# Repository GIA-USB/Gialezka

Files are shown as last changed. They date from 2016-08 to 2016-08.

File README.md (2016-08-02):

# Gialezka
Robot autónomo que realiza un recorrido sobre líneas de transmisión simuladas.

Logró el Primer Lugar en la categoría Desafío de la V Competencia Nacional de Robótica UNETBots 2015, realizada en Táchira, Venezuela.

El robot fue realizado por: Raúl Bander, Lalezka Duque, David Hernández y Catherine Lollett

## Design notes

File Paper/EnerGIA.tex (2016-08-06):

%% bare_conf.tex
%% V1.3
%% 2007/01/11
%% by Michael Shell
%% See:
%% http://www.michaelshell.org/
%% for current contact information.
%%
%% This is a skeleton file demonstrating the use of IEEEtran.cls
%% (requires IEEEtran.cls version 1.7 or later) with an IEEE conference paper.
%%
%% Support sites:
%% http://www.michaelshell.org/tex/ieeetran/
%% http://www.ctan.org/tex-archive/macros/latex/contrib/IEEEtran/
%% and
%% http://www.ieee.org/

%%*************************************************************************
%% Legal Notice:
%% This code is offered as-is without any warranty either expressed or
%% implied; without even the implied warranty of MERCHANTABILITY or
%% FITNESS FOR A PARTICULAR PURPOSE! 
%% User assumes all risk.
%% In no event shall IEEE or any contributor to this code be liable for
%% any damages or losses, including, but not limited to, incidental,
%% consequential, or any other damages, resulting from the use or misuse
%% of any information contained here.
%%
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
% the amount of white space around the subfigures. subfigure.sty is already
% installed on most LaTeX systems. The latest version and documentation can
% be obtained at:
% http://www.ctan.org/tex-archive/obsolete/macros/latex/contrib/subfigure/
% subfigure.sty has been superceeded by subfig.sty.

%\usepackage[caption=false]{caption}
%\usepackage[font=footnotesize]{subfig}
% subfig.sty, also written by Steven Douglas Cochran, is the modern
% replacement for subfigure.sty. However, subfig.sty requires and
% automatically loads Axel Sommerfeldt's caption.sty which will override
% IEEEtran.cls handling of captions and this will result in nonIEEE style
% figure/table captions. To prevent this problem, be sure and preload
% caption.sty with its "caption=false" package option. This is will preserve
% IEEEtran.cls handing of captions. Version 1.3 (2005/06/28) and later 
% (recommended due to many improvements over 1.2) of subfig.sty supports
% the caption=false option directly:
%\usepackage[caption=false,font=footnotesize]{subfig}
%
% The latest version and documentation can be obtained at:
% http://www.ctan.org/tex-archive/macros/latex/contrib/subfig/
% The latest version and documentation of caption.sty can be obtained at:
% http://www.ctan.org/tex-archive/macros/latex/contrib/caption/

% *** FLOAT PACKAGES ***
%
%\usepackage{fixltx2e}
% fixltx2e, the successor to the earlier fix2col.sty, was written by
% Frank Mittelbach and David Carlisle. This package corrects a few problems
% in the LaTeX2e kernel, the most notable of which is that in current
% LaTeX2e releases, the ordering of single and double column floats is not
% guaranteed to be preserved. Thus, an unpatched LaTeX2e can allow a
% single column figure to be placed prior to an earlier double column
% figure. The latest version and documentation can be found at:
% http://www.ctan.org/tex-archive/macros/latex/base/

%\usepackage{stfloats}
% stfloats.sty was written by Sigitas Tolusis. This package gives LaTeX2e
% the ability to do double column floats at the bottom of the page as well
% as the top. (e.g., "\begin{figure*}[!b]" is not normally possible in
% LaTeX2e). It also provides a command:
%\fnbelowfloat
% to enable the placement of footnotes below bottom floats (the standard
% LaTeX2e kernel puts them above bottom floats). This is an invasive package
% which rewrites many portions of the LaTeX2e float routines. It may not work
% with other packages that modify the LaTeX2e float routines. The latest
% version and documentation can be obtained at:
% http://www.ctan.org/tex-archive/macros/latex/contrib/sttools/
% Documentation is contained in the stfloats.sty comments as well as in the
% presfull.pdf file. Do not use the stfloats baselinefloat ability as IEEE
% does not allow \baselineskip to stretch. Authors submitting work to the
% IEEE should note that IEEE rarely uses double column equations and
% that authors should try to avoid such use. Do not be tempted to use the
% cuted.sty or midfloat.sty packages (also by Sigitas Tolusis) as IEEE does
% not format its papers in such ways.

% *** PDF, URL AND HYPERLINK PACKAGES ***
%
%\usepackage{url}
% url.sty was written by Donald Arseneau. It provides better support for
% handling and breaking URLs. url.sty is already installed on most LaTeX
% systems. The latest version can be obtained at:
% http://www.ctan.org/tex-archive/macros/latex/contrib/misc/
% Read the url.sty source comments for usage information. Basically,
% \url{my_url_here}.

% *** Do not adjust lengths that control margins, column widths, etc. ***
% *** Do not use packages that alter fonts (such as pslatex).         ***
% There should be no need to do such things with IEEEtran.cls V1.6 and later.
% (Unless specifically asked to do so by the journal or conference you plan
% to submit to, of course. )

\usepackage[pdftex]{graphicx}
\usepackage[utf8x]{inputenc}

% correct bad hyphenation here
\hyphenation{op-tical net-works semi-conduc-tor}

\begin{document}
%
% paper title
% can use linebreaks \\ within to get better formatting as desired
\title{Robot Autónomo de Inspección de Líneas de Trasmisión }

% author names and affiliations
% use a multiple column layout for up to three different
% affiliations

% conference papers do not typically use \thanks and this command
% is locked out in conference mode. If really needed, such as for
% the acknowledgment of grants, issue a \IEEEoverridecommandlockouts
% after \documentclass

% for over three affiliations, or if they all won't fit within the width
% of the page, use this alternative format:
% 
\author{\IEEEauthorblockN{Raúl Bander, Lalezka Duque, David Hernández y Catherine Lollett
\IEEEauthorblockA{Grupo de Inteligencia Artificial\\
Universidad Sim\'{o}n Bol\'{\i}var - Venezuela\\
\\ Email: \{12-11285, 12-10613, 12-10761, 09-10451\}@usb.ve}
}}

% use for special paper notices
%\IEEEspecialpapernotice{(Invited Paper)}

% make the title area
\maketitle

\begin{abstract}
%\boldmath
Con el paso del tiempo, la robótica ha adquirido un
lugar cada vez más importante en distintas actividades
humanas. De este modo, se propone una solución a través
de un robot completamente autónomo, para el problema
de la inspección de líneas de transmisión expuesto en la competencia UNETBOTS 2015.

\bigskip

Se realizará una simulación, a menor escala, del recorrido sobre cables de transmisión de electricidad, detección y reporte de la ubicación de fallas en la línea. Se simularán  
problemas como la maleza enredada en las líneas que deberán ser removidas y los lugares de desgaste del conductor que el robot deberá detectar. Por otra parte, se deberán superar los aislantes ubicados en las torres. Tomando en cuenta el diseño de la cancha y las tareas que debe realizar el robot, se propuso un diseño que permita al robot adaptarse a las condiciones del ambiente.
\end{abstract}
% IEEEtran.cls defaults to using nonbold math in the Abstract.
% This preserves the distinction between vectors and scalars. However,
% if the conference you are submitting to favors bold math in the abstract,
% then you can use LaTeX's standard command \boldmath at the very start
% of the abstract to achieve this. Many IEEE journals/conferences frown on
% math in the abstract anyway.

% no keywords

% For peer review papers, you can put extra information on the cover
% page as needed:
% \ifCLASSOPTIONpeerreview
% \begin{center} \bfseries EDICS Category: 3-BBND \end{center}
% \fi
%
% For peerreview papers, this IEEEtran command inserts a page break and
% creates the second title. It will be ignored for other modes.
\IEEEpeerreviewmaketitle

\bigskip

\section{Introducci\'{o}n}

\bigskip
% no \IEEEPARstart
%This demo file is intended to serve as a ``starter file''
%for IEEE conference papers produced under \LaTeX\ using
%IEEEtran.cls version 1.7 and later.
% You must have at least 2 lines in the paragraph with the drop letter
% (should never be an issue)
%I wish you the best of success.

Hoy en día un problema que sufre la sociedad venezolana es realizar el constante mantenimiento de las líneas de trasmisión. El problema se agudiza en las zonas que se encuentran menos pobladas. Factores como la maleza que pueda crecer en los propios cables o el constante crecimiento de árboles y vegetación alrededor pueden ser riesgosos para las líneas de transmisión. \\

En la competencia UNETBOTS 2015 se propone un modelo simplificado de un sistema de cables. Para proporcionar una solución a estos problemas, se construyó un robot autónomo que realiza la tarea de inspección requerida.

\bigskip
Durante el desarrollo del artículo se explican los diferentes aspectos tomados en consideración para la creación del robot como los componentes físicos, diseño y estrategias utilizadas a nivel de programación. Luego, se describen los diferentes problemas encontrados a lo largo del desarrollo del prototipo. 

\bigskip

\section{El Robot}

\bigskip

A continuación, se presenta una descripción de los componentes
utilizados en el desarrollo del robot, las partes fundamentales
del mismo y finalmente una descripción de los aspectos algorítmicos
importantes de la solución planteada.

\subsection{Componentes Mecánicos y Electrónicos}

\bigskip

\subsubsection{La Tarjeta}

Se escogió la tarjeta Arduino para este caso. La razón principal de esta decisión fue su fácil configuración. Sumado a lo anterior, la tarjeta posee una amplia cantidad de puertos analógicos y digitales, de modo que permite un diseño cómodo con respecto al número de sensores.

\bigskip
\subsubsection{Sensores}

\bigskip

Los sensores utilizados para poder realizar la tarea fueron:

\bigskip
\begin{itemize}

\item Se colocó un sensor QTR-1RC que distingue la reflectancia para ubicar los puntos calientes al nivel de la guaya. 

\item Para el reconocimiento de la maleza peligrosa, se utilizó un sensor ultrasonido.

\end{itemize}

\bigskip
\subsubsection{Motores}

\bigskip

\begin{itemize}
\bigskip

\item La plataforma de movimiento cuenta con dos servos; uno para cada rueda principal.

\item El robot cuenta con una sierra que es asistida por un tercer motor de corriente continua.

\end{itemize}

\bigskip

\subsection{Diseño del Robot}

\bigskip
\subsubsection{Materiales}

\bigskip

Los componentes electrónicos descritos en la sección anterior se encuentran sujetos al robot principalmente con piezas de LEGO\textregistered \vspace{2mm}  tradicionales, adicionalmente se utilizó cintas de amarre plástico para sujetar mejor las piezas de LEGO\textregistered \vspace{2mm}  entre sí y fortalecer la estructura del mismo. \\

Hacer una estructura física compuesta principalmente de piezas de LEGO\textregistered \vspace{2mm} permite hacer reconstrucciones en la estructura del robot de forma fácil, rápida y a muy bajo costo respecto al tiempo y dinero; ya que las piezas de LEGO\textregistered \vspace{2mm} se unen y despegan con facilidad y son completamente reutilizables.\\

Por otro lado, el robot debe realizar 4 tareas principales: recorrer las guayas, cortar la maleza enredada en las líneas de transmisión, detectar los puntos calientes y detectar la maleza peligrosa que pudiesen estar debajo de la guaya. \\

Para realizar estas tareas por separado se construyó un robot de manera modular con piezas de LEGO\textregistered \vspace{2mm} para acoplar fácilmente las estructuras entre sí. \\

\bigskip
\subsubsection{Diseño de la Plataforma de Tracción}

\bigskip

La estructura en la cual todos los demás componentes se acoplan y es el encargado de transportar todo el peso del robot. Está compuesto por un par de servos que alimentan unas ruedas ubicadas en la parte delantera del robot. Adicionalmente consta de ruedas traseras que sirven como punto de apoyo para el resto del cuerpo del robot. Consta de unas paredes de 30 cm formando así un cuadrado 30 x 30 cm construido enteramente con piezas de LEGO\textregistered \vspace{2mm} como se puede observar en la Figura \ref{fig:robot}.\\

\begin{figure}[htp]
	\centering
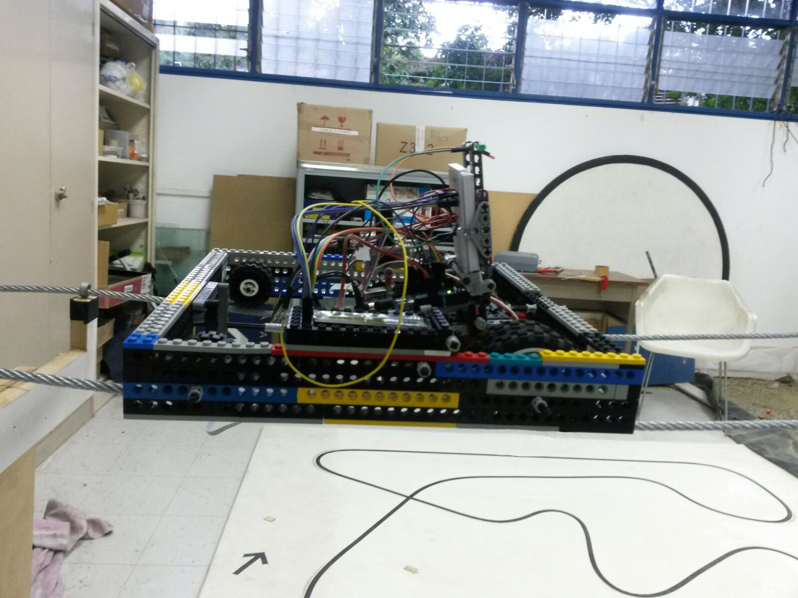
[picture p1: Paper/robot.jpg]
	
	\caption{Robot}
	\label{fig:robot}
\end{figure}

En esta superficie se encuentran el protoboard, la tarjeta y el resto de los componentes necesarios para realizar las tareas. \\

La tarjeta se encuentra sujeta a este diseño en la parte superior para facilitar la conexión de los componentes electrónicos.\\

Con el fin de conocer la distancia desde el punto de partida, tarea exigida en esta categoría, se toma como referencia las rotaciones que da el motor. 

\bigskip
\subsubsection{Diseño de la Sierra}

\bigskip

La sierra es la estructura encargada de cortar la maleza que se encuentra en las guayas que simulan los cables de electricidad. Es un motor DC que tiene indexado un disco de corte de esmeril que posee una lija de frente y desgasta el papel hasta removerlo de la línea. El motor se encuentra incorporado al robot con una caja de un solo ambiente hecha con piezas de LEGO\textregistered \vspace{2mm}. El disco se encuentra a un lado de la guaya, cerca de la misma para poder desgastar el papel de seda. La sierra se encuentra acoplado al lado derecho de la plataforma de tracción. \\

La versión actual de este componente presenta ciertos problemas que serán expuestos en la sección 3 de problemas encontrados.

\begin{figure}[htp]
	\centering
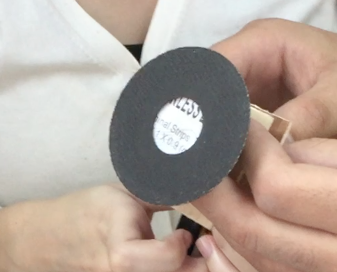
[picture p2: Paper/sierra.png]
	
	\caption{Sierra del Robot}
	\label{fig:sierra}
\end{figure}

\bigskip
\subsubsection{Diseño del Localizador de Puntos Calientes}

\bigskip

Es la estructura encargada de reconocer los puntos calientes. Consiste en una pequeña caja construida con LEGO\textregistered \vspace{2mm} donde se encuentra el sensor de reflectancia QTR-1RC, el cual detecta según un rango de números si lo que se encuentra observando es la guaya (color gris) o un punto caliente (color blanco).\\ 

El QTR-1RC se encuentra acoplado al frente del robot con la finalidad de, a parte de detectar los puntos calientes, distinguir los aislantes de forma que el robot pueda superar el obstáculo.\\

Para indicar la distancia desde la marca de salida se utilizará un display incorporado al robot. \\

\bigskip
\subsubsection{Diseño del Localizador de la Maleza en el corredor de servidumbre}

\bigskip

Es la estructura encargada de reconocer la maleza peligrosa bajo las líneas de transmisión. Consiste simplemente en un sensor de ultrasonido incorporado a la estructura móvil del robot.\\

Para mostrar la magnitud de la distancia correspondiente desde la marca de salida se utilizará el display incorporado al robot. \\

\bigskip

\subsection{Aspectos Electrónicos}
\bigskip

Entre los aspectos electrónicos destacan los siguientes:\\
 
\begin{itemize}
	\item Para reducir la cantidad de pines usados por el display se utilizó el BUS I2C.\\
	
	\item Debido al uso de un motor cuya fuente de alimentación no se encuentra regulada por el Arduino, se usó un regulador de voltaje LM7812 para estabilizar la salida de corriente.\\
	
	\item Los condensadores necesarios para el uso de ese regulador fueron de 1 $\mu$F y 0.33 $\mu$F.\\
	
	\item Al momento de detectar un punto caliente se enciende un LED rojo. Para indicar la maleza peligrosa se encenderá un LED verde. Un LED azul indicará si el robot se encuentra prendido o apagado. Cada LED lleva una resistencia de 220 $\Omega$.\\
	
	\item El robot se alimenta con 16 pilas AA.

\end{itemize}

\bigskip

\subsection{Aspectos Algorítmicos}
\bigskip

En el presente punto se desarrollarán los diversos aspectos algorítmicos del código implementado:\\ 

\begin{itemize}

	\item Debido al uso del BUS se utilizó la librería WIRE.h para poder habilitar LiquidCrystal{\_}I2C.h\\
	\item Para usar los servos, se utilizó la librería especial Servo.h.\\
	\item Una serie de condicionales fueron utilizados para aprovechar las ventajas de los sensores y resolver los problemas planteados.\\
	
\end{itemize}

\bigskip
\section{Problemas Encontrados}
\bigskip

A continuación se presentan los principales problemas encontrados
a lo largo del desarrollo del robot, en conjunto con posibles
soluciones.

\bigskip
\subsection{Problemas Estructurales}

\bigskip
Un gran problema en el diseño espacial del robot vino dado por
las limitaciones de espacio (un cubo de 30 cm$ ^{3} $). Si bien una de las ventajas de utilizar LEGO\textregistered \vspace{2mm} en la estructura del robot es que permite acoplar fácilmente las estructuras modulares. No obstante, debido a que estas piezas vienen con tamaños preestablecidos, dificulta alcanzar la precisión deseada. Esto podría resolverse con la ayuda de materiales que puedan modificarse a conveniencia.\\

Debido al peso del robot se hace difícil llegar hasta el punto más alto de la guaya.\\

\bigskip
\subsection{Problemas con la Sierra}
\bigskip

Uno de los problemas actuales de la sierra es su motor. Su peso y tamaño resulta inconveniente para el desarrollo del proyecto.\\

Se probó el uso de motores más pequeños pero la mayoría poseía no poseía suficiente torque para garantizar el avance continuo de la sierra. Los diferentes motores utilizados se muestran en la Figura \ref{fig:motor}.\\

\begin{figure}[htp]
	\centering
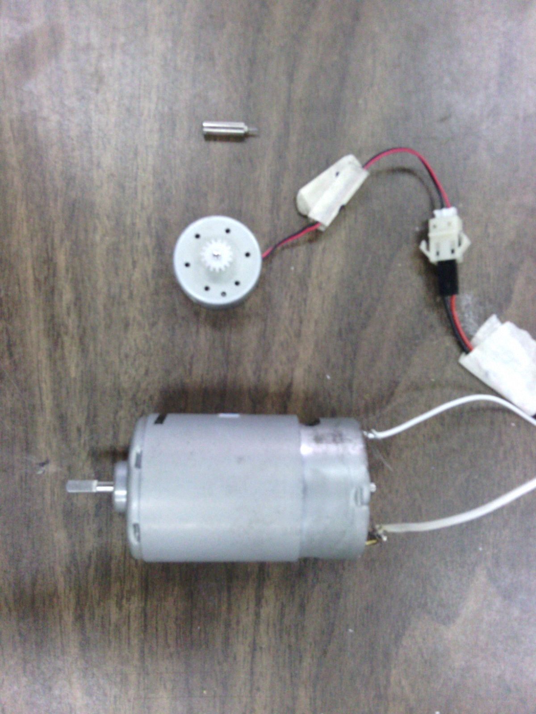
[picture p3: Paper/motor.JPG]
	
	\caption{Motores utilizados para la Sierra}
	\label{fig:motor}
\end{figure}

Por otra parte la sierra tarda un tiempo considerable en desgastar el papel de seda lo que resulta un problema significativo.\\ 

\bigskip
\subsection{Problema con el sensor de reflectancia QTR-1RC}
\bigskip

El mayor problema que se encontró con el sensor de reflectancia QTR-1RC fue que al pasar los aislantes el robot levanta gran parte de su estructura incluyendo el sensor. Esto hace que las lecturas hechas varíen en gran medida.  

\bigskip
\section{Conclusión}
\bigskip

El primer prototipo desarrollado probó ser una buena base para las siguientes etapas de desarrollo. Debido al diseño modular, los problemas que se enfrentan actualmente pueden ser atacados sin realizar fuertes cambios estructurales en el robot.\\

En la siguiente etapa, la prioridad será mejorar la subida del robot en la guaya ya que se le hace difícil llegar hasta el punto más alto de la línea de transmisión.\\

Por otra parte la sierra tarda de manera considerable en cortar el papel de seda lo que resulta un problema significativo.\\ 

Es posible que la limitación en el tamaño del robot sea una causa importante de las dificultades que se puedan presentar posteriormente.\\

Mediante el desarrollo del prototipo, se entendieron las ventajas y desventajas de variados tipos de construcción en LEGO\textregistered \vspace{2mm}, procedimientos de calibración, técnicas de detección de errores. Este conocimiento será de utilidad en la segunda etapa de desarrollo del robot.\\

\bigskip

\section*{Agradecimientos}
\bigskip

 Estamos profundamente agradecidos con todas las personas que muy amablemente donaron e hicieron posible con ello la participación en esta competencia y a la ayuda incondicional de Arturo Toro, María Victoria Jorge y María Gabriela Guzmán durante todo el proceso de construcción del robot. Para finalizar queremos agradecer los profesores Carolina Chang, Ivette Carolina Martínez y Guillermo Villegas por su guía y apoyo en todo momento. 

\bigskip
\begin{thebibliography}{1}

\bigskip
\bibitem[1]{reglas} http://www.unet.edu.ve/evento/unetbots/reglamentos/UNETBotsDesafio.pdf
\bibitem[2]{QTR}
https://www.pololu.com/product/958
\bibitem[3]{reglasg} http://www.unet.edu.ve/evento/unetbots/reglamentos/ReglamentoGeneral.pdf
\bibitem[4]{servo}
https://www.arduino.cc/en/Reference/Servo

\end{thebibliography}

\end{document}

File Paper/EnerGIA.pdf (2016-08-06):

Robot Autonomo de Inspecci ´ | on de L ´ | íneas de

# Trasmision´

Raul Bander, Lalezka Duque, David Hern ´ | andez y Catherine Lollett ´
Grupo de Inteligencia Artificial Universidad Simon Bol ´ ívar - Venezuela

Email: {12-11285, 12-10613, 12-10761, 09-10451}@usb.ve

Abstract—Con el paso del tiempo, la robotica ha adquirido un ´ lugar cada vez mas importante en distintas actividades humanas. ´
De este modo, se propone una solucion a trav ´ | es de un robot ´
completamente autonomo, para el problema de la inspecci ´ | on de ´
líneas de transmision expuesto en la competencia UNETBOTS ´ 2015.
Se realizara una simulaci ´ | on, a menor escala, del recorrido ´
sobre cables de transmision de electricidad, detecci ´ | on y reporte ´
de la ubicacion de fallas en la l ´ | ínea. Se simularan problemas como ´
la maleza enredada en las líneas que deberan ser removidas y los ´ lugares de desgaste del conductor que el robot debera detectar. ´ Por otra parte, se deberan superar los aislantes ubicados en las ´ torres. Tomando en cuenta el diseno de la cancha y las tareas ˜ que debe realizar el robot, se propuso un diseno que permita al ˜ robot adaptarse a las condiciones del ambiente.
I. INTRODUCCION´

Hoy en día un problema que sufre la sociedad venezolana es realizar el constante mantenimiento de las líneas de trasmision. El problema se agudiza en las zonas que se ´ encuentran menos pobladas. Factores como la maleza que pueda crecer en los propios cables o el constante crecimiento
de arboles y vegetaci ´ | on alrededor pueden ser riesgosos para ´
las líneas de transmision. ´

En la competencia UNETBOTS 2015 se propone un modelo simplificado de un sistema de cables. Para proporcionar una
solucion a estos problemas, se construy ´ | o un robot aut ´ | onomo ´
que realiza la tarea de inspeccion requerida. ´

Durante el desarrollo del artículo se explican los diferentes
aspectos tomados en consideracion para la creaci ´ | on del robot ´
como los componentes físicos, diseno y estrategias utilizadas ˜ a nivel de programacion. Luego, se describen los diferentes ´ problemas encontrados a lo largo del desarrollo del prototipo.

II. EL ROBOT

A continuacion, se presenta una descripci ´ | on de los com- ´
ponentes utilizados en el desarrollo del robot, las partes fundamentales del mismo y finalmente una descripcion de los ´ aspectos algorítmicos importantes de la solucion planteada. ´
A. Componentes Mecanicos y Electr ´ | onicos ´
1) La Tarjeta: Se escogio la tarjeta Arduino para este caso. ´
La razon principal de esta decisi ´ | on fue su f ´ | acil configuraci ´ | on. ´
Sumado a lo anterior, la tarjeta posee una amplia cantidad de
puertos analogicos y digitales, de modo que permite un dise ´ | | | nõ
comodo con respecto al n ´ | umero de sensores. ´
2) Sensores: Los sensores utilizados para poder realizar la tarea fueron:
- Se coloco un sensor QTR-1RC que distingue la reflectan- ´ cia para ubicar los puntos calientes al nivel de la guaya.
- Para el reconocimiento de la maleza peligrosa, se utilizó un sensor ultrasonido.
3) Motores:
- La plataforma de movimiento cuenta con dos servos; uno para cada rueda principal.
- El robot cuenta con una sierra que es asistida por un tercer motor de corriente continua.
B. Diseno del Robot ˜
1) Materiales: Los componentes electronicos descritos ´ en la seccion anterior se encuentran sujetos al robot ´ principalmente con piezas de LEGO
R | tradicionales,
adicionalmente se utilizo cintas de amarre pl ´ | astico para ´
sujetar mejor las piezas de LEGO

R entre sí y fortalecer la

estructura del mismo.

Hacer una estructura física compuesta principalmente de piezas de LEGO

R | permite hacer reconstrucciones en la
estructura del robot de forma facil, r ´ | apida y a muy bajo costo ´
respecto al tiempo y dinero; ya que las piezas de LEGO
R

se unen y despegan con facilidad y son completamente

reutilizables.

Por otro lado, el robot debe realizar 4 tareas principales: recorrer las guayas, cortar la maleza enredada en las líneas de transmision, detectar los puntos calientes y detectar la maleza ´ peligrosa que pudiesen estar debajo de la guaya.

Para realizar estas tareas por separado se construyo un ´ robot de manera modular con piezas de LEGO

R para acoplar

facilmente las estructuras entre s ´ | í.
2) Diseno de la Plataforma de Tracci ˜ | on: ´ | La estructura
en la cual todos los demas componentes se acoplan y es ´ el encargado de transportar todo el peso del robot. Está compuesto por un par de servos que alimentan unas ruedas ubicadas en la parte delantera del robot. Adicionalmente consta de ruedas traseras que sirven como punto de apoyo para el resto del cuerpo del robot. Consta de unas paredes de 30 cm formando así un cuadrado 30 x 30 cm construido enteramente con piezas de LEGO

R como se puede observar en la Figura 1.


Fig. 1. Robot

En esta superficie se encuentran el protoboard, la tarjeta y el resto de los componentes necesarios para realizar las tareas.

La tarjeta se encuentra sujeta a este diseno en la parte ˜ superior para facilitar la conexion de los componentes ´ electronicos. ´

Con el fin de conocer la distancia desde el punto de partida, tarea exigida en esta categoría, se toma como referencia las rotaciones que da el motor.

3) Diseno de la Sierra: ˜ | La sierra es la estructura encargada
de cortar la maleza que se encuentra en las guayas que simulan los cables de electricidad. Es un motor DC que tiene indexado un disco de corte de esmeril que posee una lija de frente y desgasta el papel hasta removerlo de la línea. El motor se encuentra incorporado al robot con una caja de un solo ambiente hecha con piezas de LEGO
| R . El disco se encuentra

a un lado de la guaya, cerca de la misma para poder desgastar el papel de seda. La sierra se encuentra acoplado al lado derecho de la plataforma de traccion. ´

La version actual de este componente presenta ciertos ´
problemas que seran expuestos en la secci ´ | on 3 de problemas ´
encontrados.


Fig. 2. Sierra del Robot

4) Diseno del Localizador de Puntos Calientes: ˜ | Es la
estructura encargada de reconocer los puntos calientes.
Consiste en una pequena caja construida con LEGO ˜ | R donde

se encuentra el sensor de reflectancia QTR-1RC, el cual
detecta segun un rango de n ´ | umeros si lo que se encuentra ´
observando es la guaya (color gris) o un punto caliente (color blanco).

El QTR-1RC se encuentra acoplado al frente del robot con la finalidad de, a parte de detectar los puntos calientes, distinguir los aislantes de forma que el robot pueda superar el obstaculo. ´

Para indicar la distancia desde la marca de salida se utilizara un display incorporado al robot. ´

5) Diseno del Localizador de la Maleza en el corredor ˜ de servidumbre: Es la estructura encargada de reconocer la maleza peligrosa bajo las líneas de transmision. Consiste ´ simplemente en un sensor de ultrasonido incorporado a la estructura movil del robot. ´

Para mostrar la magnitud de la distancia correspondiente desde la marca de salida se utilizara el display incorporado al ´ robot.

C. Aspectos Electronicos ´

Entre los aspectos electronicos destacan los siguientes: ´

- Para reducir la cantidad de pines usados por el display se utilizo el BUS I2C. ´
- Debido al uso de un motor cuya fuente de alimentacion´ no se encuentra regulada por el Arduino, se uso un ´ regulador de voltaje LM7812 para estabilizar la salida de corriente.
- Los condensadores necesarios para el uso de ese regulador fueron de 1 µF y 0.33 µF.
- Al momento de detectar un punto caliente se enciende un LED rojo. Para indicar la maleza peligrosa se encenderá un LED verde. Un LED azul indicara si el robot se ´ encuentra prendido o apagado. Cada LED lleva una resistencia de 220 Ω.
- El robot se alimenta con 16 pilas AA.
D. Aspectos Algorítmicos

En el presente punto se desarrollaran los diversos aspectos ´ algorítmicos del codigo implementado: ´

- Debido al uso del BUS se utilizo la librer ´ | ía WIRE.h
para poder habilitar LiquidCrystal I2C.h
- Para usar los servos, se utilizo la librer ´ | ía especial Servo.h.
- Una serie de condicionales fueron utilizados para aprovechar las ventajas de los sensores y resolver los problemas planteados.

III. PROBLEMAS ENCONTRADOS

A continuacion se presentan los principales problemas en- ´ contrados a lo largo del desarrollo del robot, en conjunto con posibles soluciones.

A. Problemas Estructurales

Un gran problema en el diseno espacial del robot vino ˜ dado por las limitaciones de espacio (un cubo de 30 cm³
). Si
bien una de las ventajas de utilizar LEGO

R en la estructura

del robot es que permite acoplar facilmente las estructuras ´ modulares. No obstante, debido a que estas piezas vienen
con tamanos preestablecidos, dificulta alcanzar la precisi ˜ | on´
deseada. Esto podría resolverse con la ayuda de materiales que puedan modificarse a conveniencia.

Debido al peso del robot se hace difícil llegar hasta el punto mas alto de la guaya. ´

B. Problemas con la Sierra

Uno de los problemas actuales de la sierra es su motor. Su peso y tamano resulta inconveniente para el desarrollo del ˜ proyecto.

Se probo el uso de motores m ´ | as peque ´ | nos pero la mayor ˜ | ía
poseía no poseía suficiente torque para garantizar el avance continuo de la sierra. Los diferentes motores utilizados se muestran en la Figura 3


Fig. 3. Motores utilizados para la Sierra

Por otra parte la sierra tarda un tiempo considerable en desgastar el papel de seda lo que resulta un problema significativo.

C. Problema con el sensor de reflectancia QTR-1RC

El mayor problema que se encontro con el sensor de ´ reflectancia QTR-1RC fue que al pasar los aislantes el robot levanta gran parte de su estructura incluyendo el sensor. Esto hace que las lecturas hechas varíen en gran medida.

IV. CONCLUSION´

El primer prototipo desarrollado probo ser una buena base ´ para las siguientes etapas de desarrollo. Debido al disenõ modular, los problemas que se enfrentan actualmente pueden ser atacados sin realizar fuertes cambios estructurales en el robot.

En la siguiente etapa, la prioridad sera mejorar la subida ´ del robot en la guaya ya que se le hace difícil llegar hasta el
punto mas alto de la l ´ | ínea de transmision. ´

Por otra parte la sierra tarda de manera considerable en cortar el papel de seda lo que resulta un problema significativo.

Es posible que la limitacion en el tama ´ | no del robot sea una ˜
causa importante de las dificultades que se puedan presentar posteriormente.

Mediante el desarrollo del prototipo, se entendieron las ventajas y desventajas de variados tipos de construccion´ en LEGO

R , procedimientos de calibracion, t ´ | ecnicas de ´
deteccion de errores. Este conocimiento ser ´ | a de utilidad en la ´
segunda etapa de desarrollo del robot.

AGRADECIMIENTOS

Estamos profundamente agradecidos con todas las personas que muy amablemente donaron e hicieron posible con ello la participacion en esta competencia y a la ayuda incondi- ´ cional de Arturo Toro, María Victoria Jorge y María Gabriela
Guzman durante todo el proceso de construcci ´ | on del robot. ´
Para finalizar queremos agradecer los profesores Carolina Chang, Ivette Carolina Martínez y Guillermo Villegas por su guía y apoyo en todo momento.

REFERENCES

[1] http://www.unet.edu.ve/evento/unetbots/reglamentos/UNETBotsDesafio.pdf
[2] https://www.pololu.com/product/958
[3] http://www.unet.edu.ve/evento/unetbots/reglamentos/ReglamentoGeneral.pdf
[4] https://www.arduino.cc/en/Reference/Servo

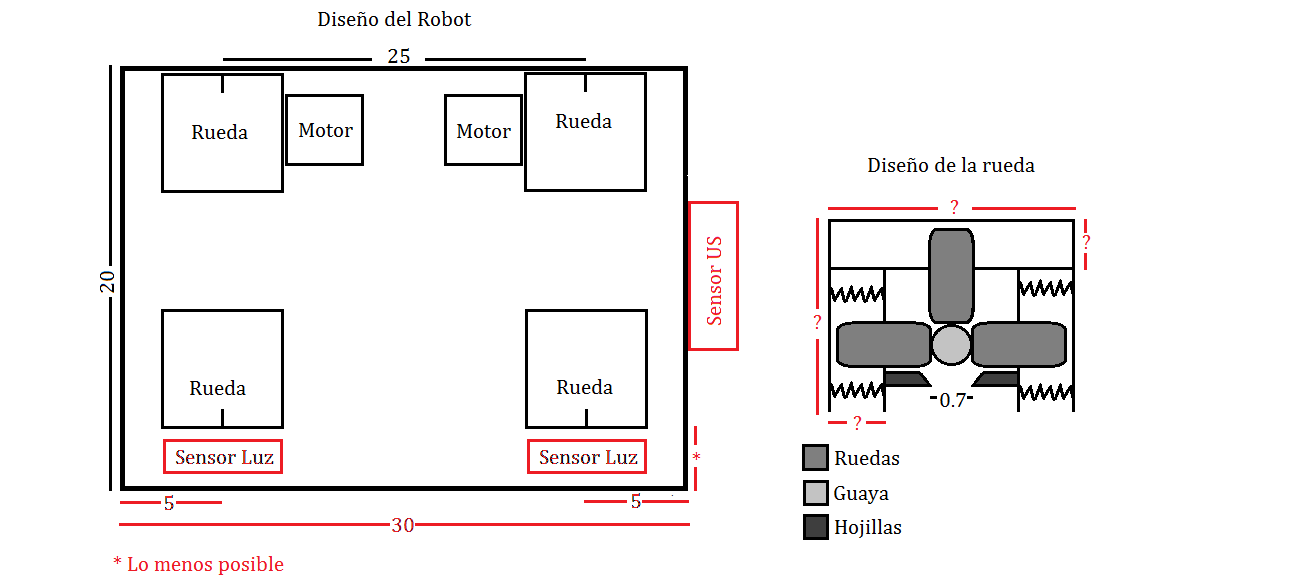
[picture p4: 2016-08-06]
Modelos/Diseño Desafio 0.bmp

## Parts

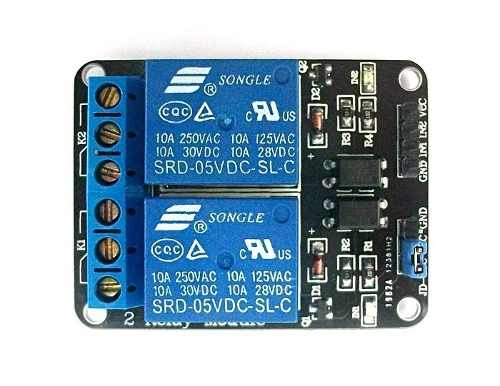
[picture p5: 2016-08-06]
Componentes/modulo-de-2-dos-reles-para-arduino-o-pic-238501-MLV20367957112_082015-O.jpg

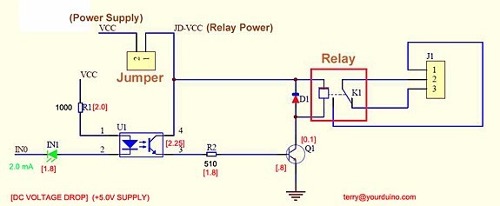
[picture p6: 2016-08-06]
Componentes/modulo-de-2-dos-reles-para-arduino-o-pic-145601-MLV20367957151_082015-O.jpg

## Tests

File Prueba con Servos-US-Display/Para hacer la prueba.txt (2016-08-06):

Este es el codigo de la prueba con el display en modulo I2C.
Tienen que agregar la libreria LiquidCrystalDisplay_I2C.
Funciona perfect!

Para usar el I2C hay que ver que número en hexadecimal usa, ya que esta es la dirección de la componente I2C. Por lo tanto se usa el código "I2C_scan" que se encuentra en la carpeta de "Desafío/Librerias/LyquidCrystalDisplay_I2C" en el IDE de Arduino.
Luego se puede usar la libreria LCD_I2C con normalidad en el IDE.
Esta tiene las mismas funciones que la libreria LCD. Solo cambia es la declaración de la libreria, según leí, esta funciona para todos los display:

LiquidCrystal_I2C   lcd(I2C_ADDR,2, 1, 0, 4, 5, 6, 7);

Donde I2C_ADDR es la dirección de la componente calculada con el código "I2C_scan".

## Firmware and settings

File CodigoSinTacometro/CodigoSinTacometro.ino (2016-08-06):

#include <Servo.h>
#include <Wire.h>
#include <LiquidCrystal_I2C.h>
#include <QTRSensors.h>

#define NUM_SENSORS   1     // number of sensors used
#define TIMEOUT       2500  // waits for 2500 microseconds for sensor outputs to go low
#define EMITTER_PIN   2     // emitter is controlled by digital pin 2
#define SIERRA        4     //Pin digital encargado de prender y apagar la cierra
#define TACOMETRO     3     //Pin SIGNAL del tacometro
#define LEDVERDE      A0
#define LEDROJO       A1

//Pines en el PCF8574(dir,en,rw,rs,d4,d5,d6,d7,bl, blpol)
LiquidCrystal_I2C lcd(0x27, 2, 1, 0, 4, 5, 6, 7, 3, POSITIVE);

Servo myservo1;
Servo myservo0;

long distancia;
long tiempo;
bool bqtr;

// Sensor QTR-1RC al pin 9
QTRSensorsRC qtrrc((unsigned char[]) {9}, NUM_SENSORS, TIMEOUT, EMITTER_PIN); 
unsigned int sensorValues[NUM_SENSORS];

void setup(){
  bqtr = false;
  //Serial.begin(9600);
  pinMode(7, OUTPUT); /*Activación del pin 7 como salida: para el pulso ultrasónico (Trigger)*/
  pinMode(8, INPUT); /*Activación del pin 8 como entrada: tiempo del rebote del ultrasonido (Echo)*/
  pinMode(LEDROJO, OUTPUT); // Led Rojo
  pinMode(LEDVERDE, OUTPUT); // Led Verde  
  lcd.begin(16,2);
  myservo0.attach(10);
  myservo1.attach(6);

}

void loop(){
   
  qtrrc.read(sensorValues);
  lcd.setCursor(0,1);
  //Serial.print(dist);
  lcd.print(sensorValues[0]);
  myservo0.write(-180);
  myservo1.write(180);
  if(sensorValues[0]<=200 && bqtr == false){
    bqtr = true;
    digitalWrite(LEDROJO, HIGH);   // set the LED Red on
    myservo0.detach();
    myservo1.detach();
    lcd.clear();
    lcd.print("Pto C:");
    lcd.print(" cm");
    lcd.setCursor(0,1);
    lcd.print(sensorValues[0]);
    delay(10000);
    lcd.clear();
    myservo0.attach(10);
    myservo1.attach(6);
    myservo0.write(-180);
    myservo1.write(180);
    digitalWrite(LEDROJO, LOW);    // set the LED off
  }
  if (sensorValues[0] > 200){
    bqtr = false;
  }
  digitalWrite(7,LOW); /*Por cuestión de estabilización del sensor*/
  digitalWrite(7, HIGH); /*Envío del pulso ultrasónico*/
  
  tiempo = pulseIn(8, HIGH); /*Función para medir la longitud del pulso entrante. 
                               Mide el tiempo que transcurrido entre el envío
                               del pulso ultrasónico y cuando el sensor recibe el rebote, 
                               es decir: desde que el pin 12 empieza a
                               recibir el rebote, HIGH, hasta que deja de hacerlo, LOW, 
                               la longitud del pulso entrante*/
  
  distancia= int(tiempo/58); /*fórmula para calcular la distancia obteniendo un valor entero*/
  // Vegetacion en el piso
  if(20<=distancia && distancia<=40){
    digitalWrite(LEDVERDE, HIGH);   // set the LED Green on
    myservo0.detach();
    myservo1.detach();
    lcd.clear();
    lcd.print("V:");
    lcd.print("cm");
    delay(10000);
    lcd.clear();
    myservo0.attach(10);
    myservo1.attach(6);
    myservo0.write(-180);
    myservo1.write(180);
    digitalWrite(LEDVERDE, LOW);    // set the LED off
  }
    if(sensorValues[0]<=200 && bqtr == false){
    bqtr = true;
    digitalWrite(LEDROJO, HIGH);   // set the LED Red on
    myservo0.detach();
    myservo1.detach();
    lcd.clear();
    lcd.print("Pto C:");
    lcd.print(" cm");
    lcd.setCursor(0,1);
    lcd.print(sensorValues[0]);
    delay(10000);
    lcd.clear();
    myservo0.attach(10);
    myservo1.attach(6);
    myservo0.write(-180);
    myservo1.write(180);
    digitalWrite(LEDROJO, LOW);    // set the LED off
  }
  if (sensorValues[0] > 200){
    bqtr = false;
  }
}

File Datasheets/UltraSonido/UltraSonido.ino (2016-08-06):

/*
Generic example for the SRF modules 02, 08, 10 and 235.
Only the SRF08 uses the light saensor so when any other 
range finder is used with this code the light reading will 
be a constant value. 
*/

#include <Wire.h>
#include <SoftwareSerial.h>

#define LCD_RX              0x02                                   // Software serial pin for rx
#define LCD_TX              0x03                                   // Software serial pin for tx
#define SRF_ADDRESS         0x70                                   // Address of the SRF08
#define CMD                 (byte)0x00                             // Command byte, values of 0 being sent with write have to be masked as a byte to stop them being misinterpreted as NULL this is a bug with arduino 1.0
#define LIGHTBYTE           0x01                                   // Byte to read light sensor
#define RANGEBYTE           0x02                                   // Byte for start of ranging data
#define LCD03_CLEAR         0x0C                                   // Byte to clear LCD03 screen
#define LCD03_SET_CUR       0x02                                   // Byte to tell LCD03 we wish to move cursor
#define LCD03_HIDE_CUR      0x04                                   // Byte to hide the cursor

SoftwareSerial lcd_03 =  SoftwareSerial(LCD_RX, LCD_TX);    // defines a new software serial port for lcd_03

byte highByte = 0x00;                             // Stores high byte from ranging
byte lowByte = 0x00;                              // Stored low byte from ranging

void setup(){
  
  lcd_03.begin(9600);                             // Begins serial port for LCD_03
  Wire.begin();                               
  delay(100);                                     // Waits to make sure everything is powered up before sending or receiving data
  
  lcd_03.write(LCD03_CLEAR);
  lcd_03.write(LCD03_HIDE_CUR);
  lcd_03.println("SRF02/08/10/235");
  
  int softRev = getSoft();                        // Calls function to get software revision
  lcd_03.write(LCD03_SET_CUR);
  lcd_03.write(61);                               // Move cursor
  lcd_03.print("Software version: ");
  lcd_03.print(softRev, DEC);                     // Print softRev to LCD03
    
}

void loop(){
  
  int rangeData = getRange();                     // Calls a function to get range
  lcd_03.write(LCD03_SET_CUR);
  lcd_03.write(21);                               // Move cursor to space 21
  lcd_03.print("Range = ");
  lcd_03.print(rangeData, DEC);                   // Print rangeData to LCD03
  lcd_03.print("   ");                            // Print some spaces to slear spaces after data
 
  int lightData = getLight();                     // Call function to get light reading and store in lightData
  lcd_03.write(LCD03_SET_CUR);
  lcd_03.write(41);                               // Move cursor to space 41
  lcd_03.print("light = ");
  lcd_03.print(lightData, DEC);                   // Display lightData
  lcd_03.print("  ");                             // Print some spaces to slear spaces after data 
  
 delay(100);                                      // Wait before looping
}

int getRange(){                                   // This function gets a ranging from the SRF08
  
  int range = 0; 
  
  Wire.beginTransmission(SRF_ADDRESS);             // Start communticating with SRF08
  Wire.write(CMD);                                 // Send Command Byte
  Wire.write(0x51);                                // Send 0x51 to start a ranging
  Wire.endTransmission();
  
  delay(100);                                      // Wait for ranging to be complete
  
  Wire.beginTransmission(SRF_ADDRESS);             // start communicating with SRFmodule
  Wire.write(RANGEBYTE);                           // Call the register for start of ranging data
  Wire.endTransmission();
  
  Wire.requestFrom(SRF_ADDRESS, 2);                // Request 2 bytes from SRF module
  while(Wire.available() < 2);                     // Wait for data to arrive
  highByte = Wire.read();                          // Get high byte
  lowByte = Wire.read();                           // Get low byte

  range = (highByte << 8) + lowByte;               // Put them together
  
  return(range);                                   // Returns Range
}

int getLight(){                                    // Function to get light reading
  
  Wire.beginTransmission(SRF_ADDRESS);
  Wire.write(LIGHTBYTE);                           // Call register to get light reading
  Wire.endTransmission();
  
  Wire.requestFrom(SRF_ADDRESS, 1);                // Request 1 byte
  while(Wire.available() < 0);                     // While byte available
  int lightRead = Wire.read();                     // Get light reading
    
  return(lightRead);                               // Returns lightRead
  
}

int getSoft(){                                     // Function to get software revision
  
  Wire.beginTransmission(SRF_ADDRESS);             // Begin communication with the SRF module
  Wire.write(CMD);                                 // Sends the command bit, when this bit is read it returns the software revision
  Wire.endTransmission();
  
  Wire.requestFrom(SRF_ADDRESS, 1);                // Request 1 byte
  while(Wire.available() < 0);                     // While byte available
  int software = Wire.read();                      // Get byte
    
  return(software);                               
  
}

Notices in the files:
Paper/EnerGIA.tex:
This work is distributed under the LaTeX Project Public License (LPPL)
